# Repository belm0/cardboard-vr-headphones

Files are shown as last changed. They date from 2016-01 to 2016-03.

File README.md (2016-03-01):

# Cardboard headphones:  DIY headphones for Cardboard VR viewers

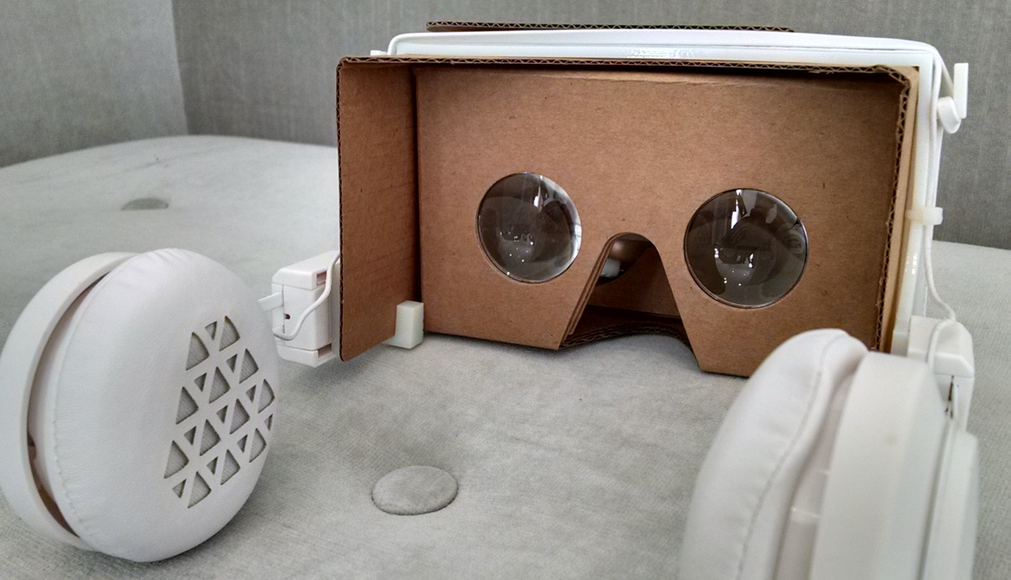
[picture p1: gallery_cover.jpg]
Cardboard VR headphones
[ more photos](https://goo.gl/photos/ggecJdJPGQ1fHz2C6 "Go to photo gallery")

**Immersive audio for Cardboard VR without sacrificing easy on & off**

Google Cardboard is great-- a simple VR experience that's easily shared.  Hand it to friends or relatives and watch them be amazed.  But things get complicated when you want to include audio in the experience:  it's awkward to exchange the headphones and viewer without dropping something, getting cords tangled, or defeating the spatialized sound goodness by crossing the left and right channels.  In the spirit of Google's Cardboard, **_Cardboard headphones_** enables VR with immersive audio that is accessible, low cost, and can be worn and removed effortlessly.

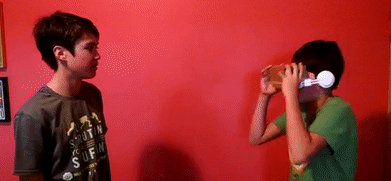
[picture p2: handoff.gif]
Handoff animation


|<span style="color: brown">Related news</span>
|------------
|[Official "Google Cardboard" now on sale](https://store.google.com/product/google_cardboard?utm_source=google-cardboard)— just add headphones!
|[Spatial audio comes to the Cardboard SDK](http://googledevelopers.blogspot.com/2016/01/spatial-audio-comes-to-cardboard-sdk.html)— you're using your viewer with headphones, right?

## What is this project exactly?

Intended for do-it-yourself types, this project publishes the design for a 3D printed part which mates off-the-shelf headphones to the Cardboard viewer.  *Cardboard headphones* attaches easily to the VR viewer, has adjustable ear depth, folds, accommodates cord slack, and supports phones with top or bottom headphone jack placement.

## What Cardboard VR viewers will this work with?

The headphone frame is designed for the "New Cardboard" VR viewer which Google gave away at their I/O 2015 event and subsequently open-sourced.  Google and several manufacturers sell viewers based on this design, namely _Google Cardboard_, _Knox V2_, _I AM CARDBOARD V2_, and _Unofficial Cardboard 2.0_ which are listed at [Get Cardboard](https://www.google.com/get/cardboard/get-cardboard/).

## What headphones will this work with?

The current design is for a specific pair of JLab Audio on-ear headphones (INTRO model), available for about 20 USD.  Several factors went into selecting this model among tested candidates:  price and availability, sound quality, ease of hacking, slack between left/right ear connection, comfort, and adjustability.  You may find these headphones have a marginal volume level due to their high impedance-- and fidelity could be better-- but they work well considering all the factors.

Of course if you're handy with 3D modeling, feel free to customize the design for other headphones.  Please share your results!

## Deliverables

* [Frame STL file](v2_jlab_intro/cardboard_headphones_frame.stl) (for 3D printing)
* [Assembly instructions](v2_jlab_intro/assembly.md)
* [Frame source model](https://tinkercad.com/things/i3NaLufb8T3) (hosted at Tinkercad)

## Disclaimers

No guarantee is made that the design will work with your headphones and viewer.  Modifying your headphones as described will void your manufacturer's warranty.  *_Cardboard headphones_* is not a Google project.

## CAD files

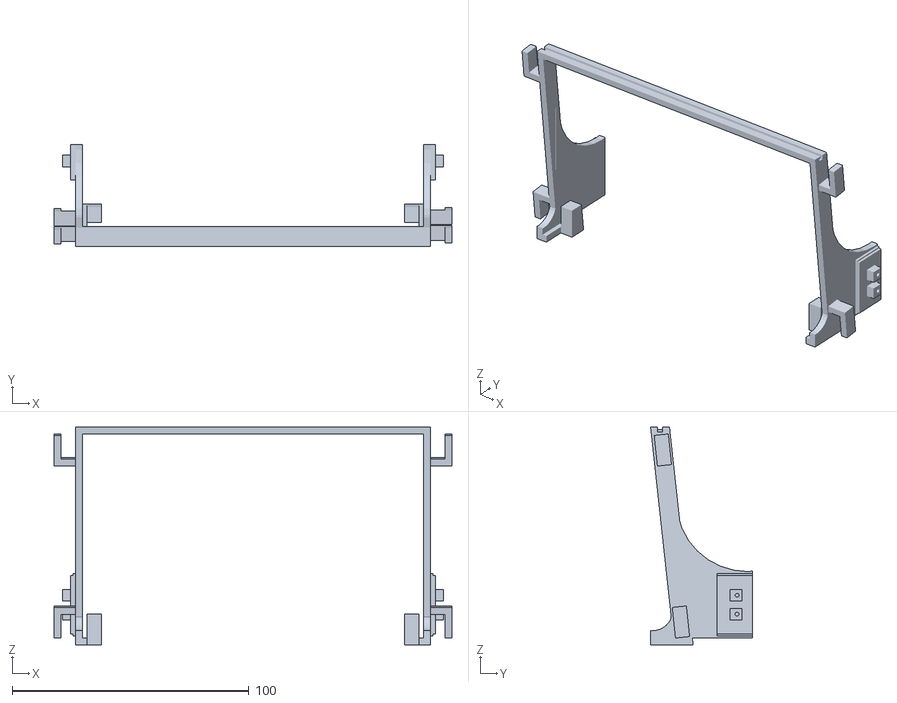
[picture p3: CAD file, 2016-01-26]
v2_jlab_intro/cardboard_headphones_frame.stl
168.0 x 43.0 x 92.0

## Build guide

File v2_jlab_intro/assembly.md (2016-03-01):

# Assembly instructions

Following are instructions for sourcing components and assembling a _Cardboard headphones_ VR viewer.  See the [home page](../../../) for more info about this project.

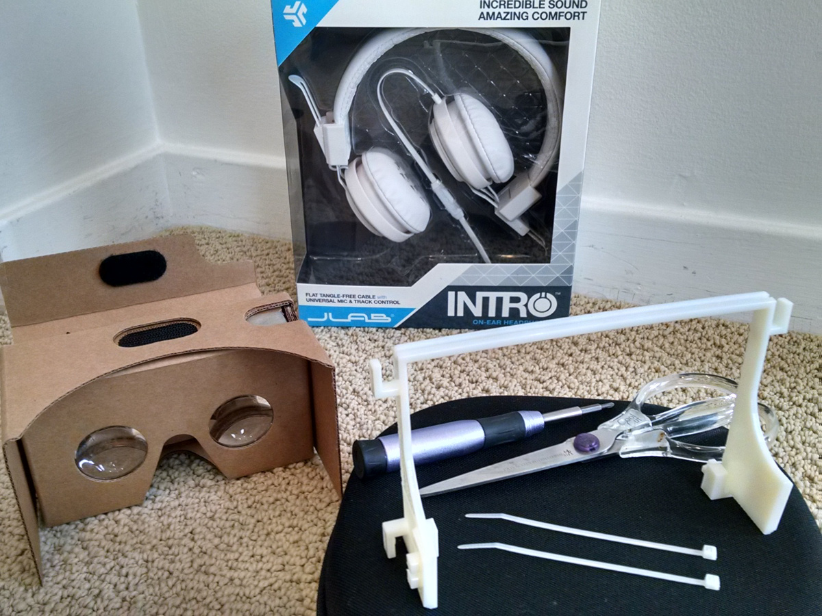
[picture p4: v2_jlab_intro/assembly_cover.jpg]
Assembly cover
[ assembly photos](https://goo.gl/photos/LNsYvQ1QFXjgn7276 "Go to assembly photo gallery")

## What you'll need

* **Cardboard VR viewer** adhering to Google's "New Cardboard" open source design.  By a ready-made viewer-- _Google Cardboard_, _Knox V2_, _I AM CARDBOARD V2_, or _Unofficial Cardboard 2.0_ listed at [Get Cardboard](https://www.google.com/get/cardboard/get-cardboard/)-- or [make your own](https://www.google.com/get/cardboard/manufacturers/).
* **headphones** - JLab Audio "INTRO" headphones.  Available from [JLab directly](http://www.jlabaudio.com/products/intro-on-ear-headphone?variant=940963049), Amazon, Newegg, etc.
* **_Cardboard headphones_ frame** - use your favorite 3D printing service to make a copy of the [frame part](cardboard_headphones_frame.stl) in ABS plastic material
* **small phillips head screwdriver (#0)**
* **scissors**
* **small cable ties or tape**

## Steps

Be sure to refer to the [assembly photo gallery](https://goo.gl/photos/LNsYvQ1QFXjgn7276).  Photo descriptions are available in the gallery's "info" panel.

1. **Prepare headphones**
  1. **remove headband assembly**
    1. on each ear of the headphones, remove 2 screws which secure the headband and detach the headband (except for the connecting cord).  Save the screws since they'll be reused later.
    1. cut across full length of the headband with scissors to free the connecting cord
  1. **re-route connecting cord** - to have sufficient slack in the connecting cord it's necessary to remove the cord from the hinge assembly of each ear
    1. remove two screws which secure the hinge assembly
    1. with the hinge open and the speaker facing down, open the hinge assembly
    1. remove the glued connecting cord with gentle force and reassemble the hinge.  Be sure the clear plastic friction gliders on the headphone arms are reseated correctly.
1. **Attach headphones to frame**
  1. **mate left / right headphone assemblies to frame**
    1. for the **right side** (having the cord which connects to phone-- see photos), line up the headphone assembly's mount with the corresponding holes of the _Cardboard headphones_ frame.  Make sure the mount sits flush on the frame.
    1. fasten headphone assembly to frame using screws remaining from removal of the headband.  Don't over-tighten.
    1. repeat for left side
  1. **route the headphone right/left connecting cord**
    1. run the cord inside the channel on the top of the _Cardboard headphones_ frame and equalize the cord slack
    1. fasten the cord to sides of the frame using cable ties or tape
  1. **eliminate earpiece toe-in** - bend the metal arms slightly so that earpieces are parallel to each other.  This improves ease of on/off and headphone fit.
1. **Attach _Cardboard headphones_ to viewer**
  1. position the frame and the edge of the viewer, ensuring the top corners of the viewer fit within the frame and the sides of the viewer slip into the lower frame channels
  1. using your index fingers and thumbs, slide the frame equally on both sides until it stops.  The lower part of the frame should be flush with the viewer's lens panel, and the top part of the frame should be just at the edge of the viewer's button
1. **Route audio cord**
  1. decide whether you want the headphone jack to be on the left or right side (based on your phone having top or bottom audio jack, respectively)
  1. with headphone arms fully extended, route the audio cord using brackets on the _Cardboard headphones_ frame as needed.  If you need the jack on the left side, run the cord along the top of the frame (pictured).

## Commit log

2016-01-26 Initial commit.
    [cardboard_headphones_frame.stl]
2016-01-27 Docs: add home page link to assembly intro.
